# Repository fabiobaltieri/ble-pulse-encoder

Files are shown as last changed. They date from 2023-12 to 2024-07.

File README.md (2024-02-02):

# BLE Pulse Encoder

A replacement board, firmware and holder for converting a 60mm pulse encoder
jog wheel to Bluetooth Low Energy.

## License (firmware)

This program is free software: you can redistribute it and/or modify
it under the terms of the GNU General Public License as published by
the Free Software Foundation, either version 3 of the License, or
(at your option) any later version.

## License (hardware)

Hardware files are licensed under a
Creative Commons Attribution-ShareAlike 4.0 International License.

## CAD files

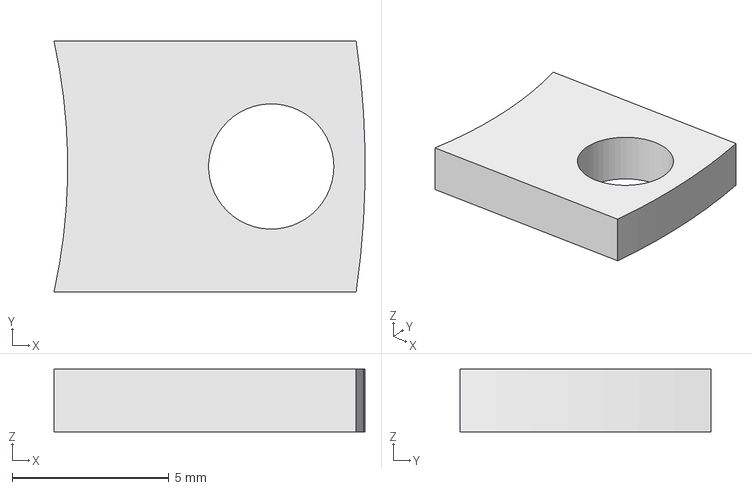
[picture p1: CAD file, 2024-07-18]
cad/tab.FCStd
9.93 x 8.00 x 2.00 mm

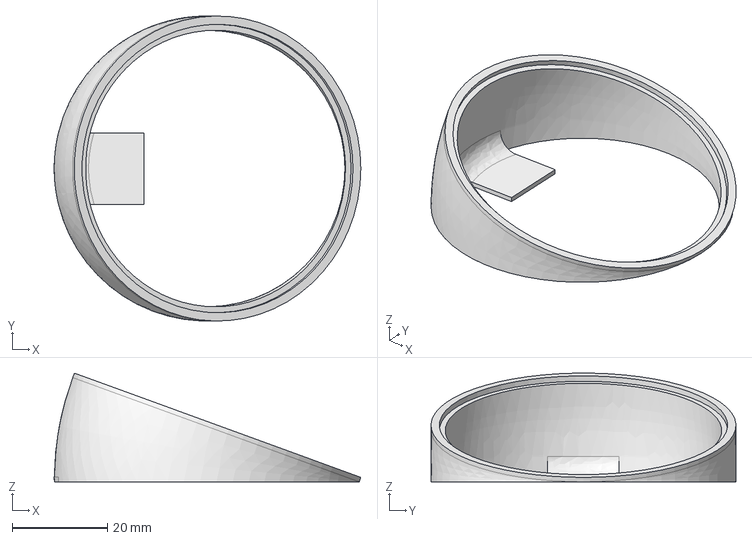
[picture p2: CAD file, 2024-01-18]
cad/base.FCStd
64.3 x 64.0 x 22.8 mm

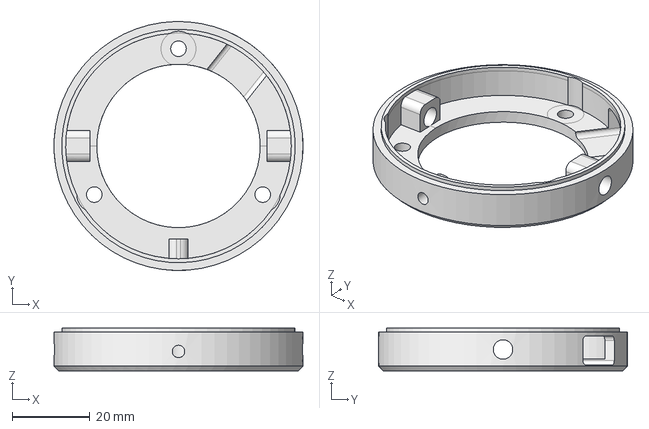
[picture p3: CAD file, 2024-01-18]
cad/top.FCStd
64.0 x 64.0 x 11.0 mm

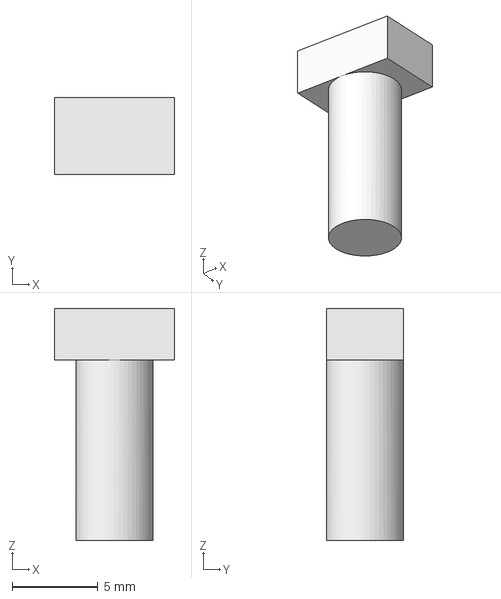
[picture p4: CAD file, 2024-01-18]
cad/button.FCStd
7.00 x 4.50 x 13.5 mm

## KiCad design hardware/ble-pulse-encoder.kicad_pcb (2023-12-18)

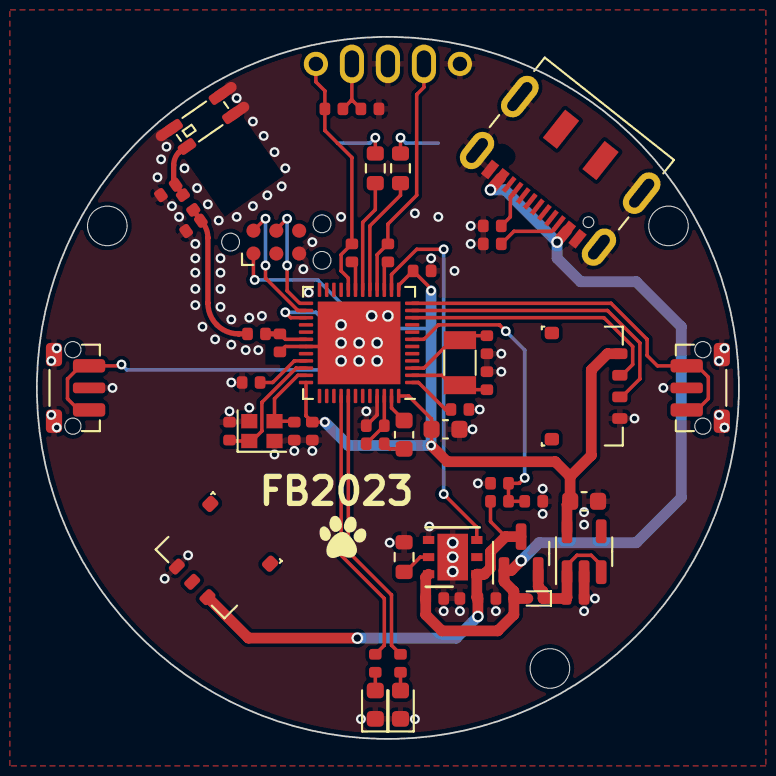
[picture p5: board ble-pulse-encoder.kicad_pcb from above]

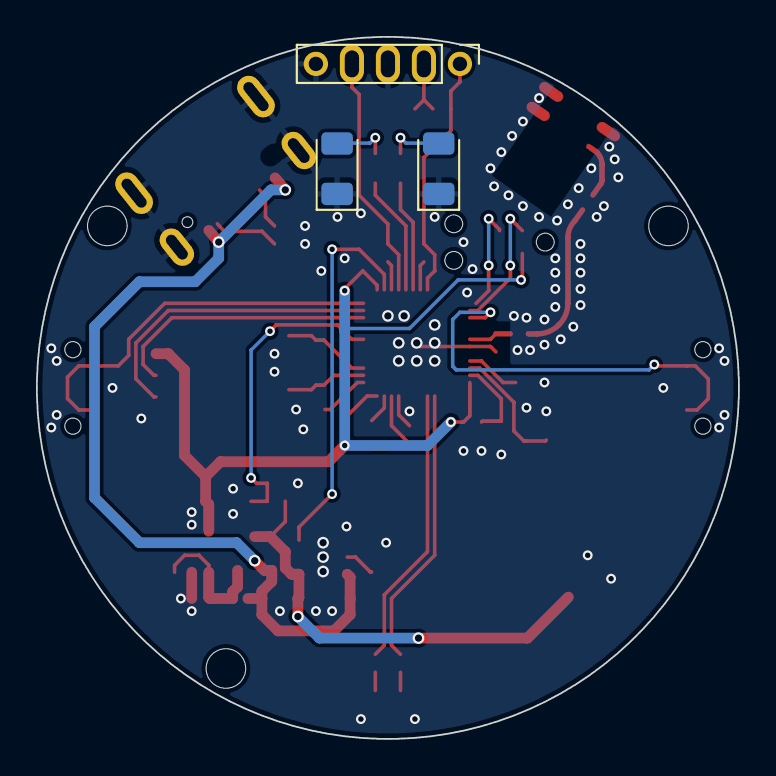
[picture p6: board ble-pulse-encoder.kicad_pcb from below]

Board: 2 copper layers, 39.0 x 39.0 mm, 58 parts (3 on the bottom side), 41 nets.

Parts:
AE1: 2450AT18D0100001; 2450AT18D0100001-L
C1, C2, C3, C4: 12p; C_0402_Worthington
C5, C6, C17: 1u; C_0402_Worthington
C7: 100p; C_0402_Worthington
C8, C9, C10, C12, C15: 100n; C_0402_Worthington
C11: 4.7u; C_0603_1608Metric
C13: 0.8p; C_0402_Worthington
C14, C16: TBD; C_0402_Worthington
C18: 10u; C_0603_1608Metric
D2: Green; LED_0603_1608Metric
D3: 1SS416; D_SOD-923
D4, D5: IR; LED_1206_3216Metric
D6: Yellow; LED_0603_1608Metric
H1, H2, H3: MountingHole_2.2mm_M2
J1: Conn_01x05; PinHeader_1x05_P2.00mm_Vertical
J2: EZmate-3
J3: EZmate-4
J4: TC2030-IDC-NL; Tag-Connect_TC2030-IDC-NL_2x03_P1.27mm_Vertical
J6: USB_C_Receptacle_USB2.0; USB_C_Receptacle_JAE_DX07S016JA1R1500
L1: 15n; L_0402_Worthington
L2: 10u; L_0603_1608Metric
L3: 3.9n; L_0402_Worthington
L4: 0; L_0402_Worthington
Q1: BSS84; SOT-23
R1: 2k2; R_0603_1608Metric
R2, R14: 5.1k; R_0402_Worthington
R3, R4: 560k; R_0402_Worthington
R5, R11, R12: 10k; R_0402_Worthington
R6, R13: 1k; R_0402_Worthington
R9, R10: 470; R_0603_1608Metric
R15, R16: 0; R_0402_Worthington
SW1, SW2: SW_Push; SW_Push_1P1T-MP_NO_Horizontal_Alps_SKRTLAE010
U1: STBC08; DFN-6-1EP_3x3mm_P0.95mm_EP1.7x2.6mm
U2: nRF52832-QFxx; QFN-48-1EP_6x6mm_P0.4mm_EP4.6x4.6mm
U3: TPS7A0333DBVR; SOT-23-5
Y1: 32.768kHz; Crystal_SMD_3215-2Pin_3.2x1.5mm
Y2: 32MHz; Crystal_SMD_2016-4Pin_2.0x1.6mm

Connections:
+3V3: C8.1, C10.1, C11.1, C18.1, J3.1, J4.1, U2.13 (VDD), U2.36 (VDD), U2.48 (VDD), U3.5 (OUT)
+5V: C6.1, D3.2 (A), J6.A4 (VBUS), J6.A9 (VBUS), J6.B4 (VBUS), J6.B9 (VBUS), Q1.1 (G), R5.1, U1.6 (VCC)
+BATT: C12.1, J2.1, Q1.3 (D), R3.1, U1.1 (BAT)
/ADC_VBATT: C15.1, R3.2, R4.1, U2.7 (P0.05/AIN3)
/ANT: C13.1, L3.2, U2.30 (ANT)
/CHRG: U1.3 (CHRG), U2.14 (P0.11)
/D0_PWR: R10.1, U2.17 (P0.14)
/D1_PWR: R9.1, U2.18 (P0.15)
/LED_A: R6.1, U2.40 (P0.28/AIN4)
/LED_B: R13.1, U2.41 (P0.29/AIN5)
/NRF_SWCLK: J4.4, U2.25 (SWDCLK)
/NRF_SWDIO: J4.2, U2.26 (SWDIO)
/PH0_PWR: R11.1, U2.15 (P0.12)
/PH0_SENSE: J1.4, R11.2, U2.16 (P0.13)
/PH1_PWR: R12.1, U2.19 (P0.16)
/PH1_SENSE: J1.1, R12.2, R15.1, U2.20 (P0.17)
/SW_A: SW1.1, U2.27 (P0.22)
/SW_B: SW2.1, U2.12 (NFC2/P0.10)
/UART_RX: J3.2, U2.10 (P0.08)
/UART_TX: J3.3, U2.11 (NFC1/P0.09)
/XL1: C2.1, U2.2 (P0.00/XL1), Y1.2
/XL2: C4.1, U2.3 (P0.01/XL2), Y1.1
GND: AE1.2 (Shield), C1.2, C2.2, C3.2, C4.2, C5.2, C6.2, C7.2, C8.2, C9.2, C10.2, C11.2, C12.2, C13.2, C14.2, C15.2, C16.2, C17.2, C18.2, D2.1 (K), D4.1 (K), D5.1 (K), D6.1 (K), J1.3, J1.5, J2.3, J3.4, J4.5, J6.A1 (GND), J6.A12 (GND), J6.B1 (GND), J6.B12 (GND), J6.S1 (SHIELD), R1.2, R2.2, R4.2, R5.2, R14.2, R16.2, SW1.2, SW1.MP, SW2.2, SW2.MP, U1.4 (GND), U1.7 (TH), U2.31 (VSS), U2.45 (VSS), U2.49 (VSS), U3.2 (GND), Y2.2, Y2.4
unnamed: AE1.1 (A), C16.1, L4.1
unnamed: C14.1, L3.1, L4.2
unnamed: D2.2 (A), R6.2
unnamed: D4.2 (A), R9.2
unnamed: D5.2 (A), R10.2
unnamed: D6.2 (A), R13.2
unnamed: J1.2, R15.2, R16.1
unnamed: J6.A5 (CC1), R14.1
unnamed: J6.B5 (CC2), R2.1
unnamed: L1.2, L2.2
unnamed: R1.1, U1.5 (PROG)
unnamed: L2.1, U2.47 (DCC)
unnamed: C9.1, U2.1 (DEC1)
unnamed: C7.1, U2.33 (DEC3)
unnamed: C5.1, L1.1, U2.46 (DEC4)
unnamed: C1.1, U2.34 (XC1), Y2.1
unnamed: C3.1, U2.35 (XC2), Y2.3
VCC: C17.1, D3.1 (K), Q1.2 (S), U3.1 (IN), U3.3 (EN)

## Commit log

2023-11-26 hw: initial import
    [ble-pulse-encoder.kicad_pcb, ble-pulse-encoder.kicad_sch]
2023-12-07 hw: few p/n tweaks
    [ble-pulse-encoder.kicad_sch]
2023-12-13 hw: assembly notes
    [ble-pulse-encoder.kicad_pcb, ble-pulse-encoder.kicad_sch]
2023-12-13 fw: add input shell, set the led pins to high drive
2023-12-13 fw: set the chrg pin
2023-12-15 fw: add a couple labels
2023-12-17 fw: fix adc channel
2023-12-17 fw: add bas adc
2023-12-17 hw: add note about missing vbatt line
    [ble-pulse-encoder.kicad_sch]
2023-12-18 hw: copy r0 files to r0/
    [ble-pulse-encoder.kicad_pcb, ble-pulse-encoder.kicad_sch]
2023-12-18 hw: r1
    [ble-pulse-encoder.kicad_pcb, ble-pulse-encoder.kicad_sch]
2023-12-31 hw: change D2 to blue
    [ble-pulse-encoder.kicad_sch]
2024-01-18 cad: add some models
    [base.FCStd, button.FCStd, top.FCStd]
2024-01-18 cad: add some nut relief
    [top.FCStd]
2024-01-18 cad: base, bigger fillet
    [base.FCStd]
2024-01-23 fw: swap left and right buttons
2024-01-23 fw: add charging led handler
2024-03-03 fw: use DT_PARENT to find the leds device
2024-03-05 fw: fix middle button code
2024-07-18 add tab cad file
    [tab.FCStd]
